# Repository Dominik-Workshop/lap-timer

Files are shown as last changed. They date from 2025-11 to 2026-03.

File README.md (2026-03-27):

# Lap Timer

 

<p align="center">
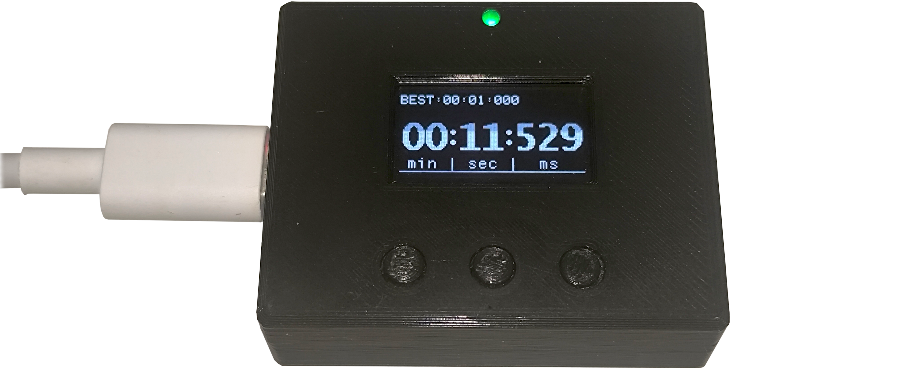
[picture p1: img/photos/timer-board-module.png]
Hero image
  
</p>

## Overview

Compact and portable **lap timer**, capable of measuring time on:

- **Closed-loop tracks** (1-gate mode)
- **Start/finish tracks** (2-gate mode)

Infrared light barriers are used as optical triggers to detect when an object crosses the start or finish line.

### Key Features

- **High accuracy** using STM32 hardware timers
- **OLED display** for showing lap times
- **Two operating modes:** 1-gate or 2-gate
- **Modulated IR system (38 kHz)** for ambient light immunity

## Project Status

**Design:** ✅ --> **Fabrication & Assembly:** ✅ --> **Bring-up:** ✅

## Electronics

Simplified arhitecture of the **Lap Timer** is shown on the block diagram bellow:
Block diagram

This project contains 3 custom PCBs:

- [**Timer board**](/pcb/timer-board/): main PCB of the system, responsible for time measurement and displaying results

<!-- <p align="center">
  <img src="images/renders/timer-board.png" width=50% alt="Timer board render"> 
</p> -->

- [**Transmitter board**](/pcb/transmitter-board/): generates the modulated IR light beam for the optical barrier

<!-- <p align="center">
  <img src="images/renders/transmitter-board.png" width=50% alt="Transmitter board render"> 
</p> -->

- [**Receiver board**](/pcb/receiver-board/): (used only in 2-gate mode) detects the IR signal and triggers the timer

<!-- <p align="center">
  <img src="images/renders/receiver-board.png" width=50% alt="Receiver board render"> 
</p> -->

## Mechanical

Each board has a custom-designed **3D printed enclosure**.

## Used Tools

- [KiCad](https://www.kicad.org/) - Schematic and PCB design
- [Autodesk Fusion 360](https://www.autodesk.com/products/fusion-360/) - 3D modeling
- [STM32CubeIDE](https://www.st.com/en/development-tools/stm32cubeide.html) - STM32 firmware development (build/flash/debug)

## Authors

- [**Dominik Pluta**](https://github.com/Dominik-Workshop):
  - **Responsibility**: [**Timer board**](/pcb/timer-board/)
- [**Mateusz Gwioździk**](https://github.com/Nojilim):
  - **Responsibility**: [**Transmitter board**](/pcb/transmitter-board/)
- [**Radek Mierzwa**](https://github.com/Radek278):
  - **Responsibility**: [**Receiver board**](/pcb/receiver-board/)

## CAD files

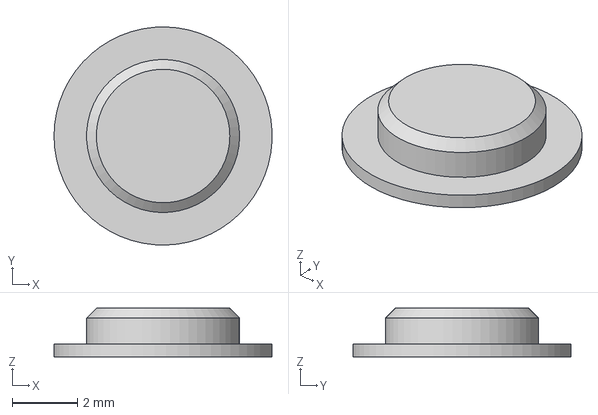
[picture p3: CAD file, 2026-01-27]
3d-models/timer-board-button.step
6.70 x 6.70 x 1.50 mm

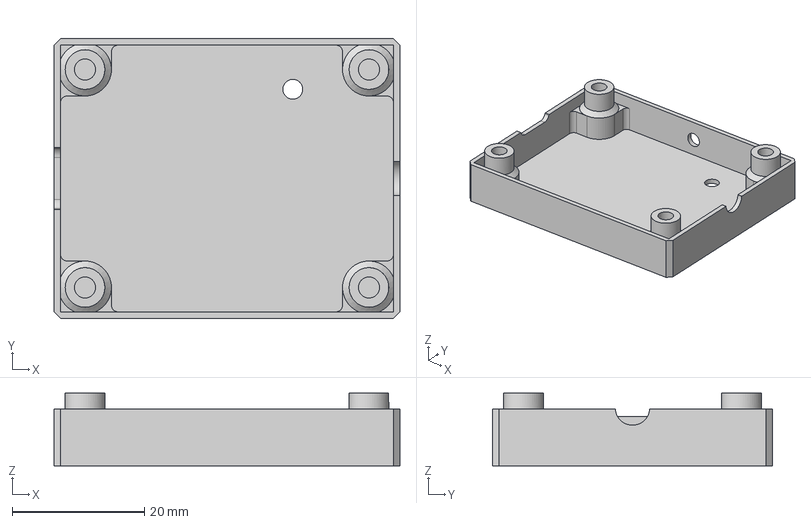
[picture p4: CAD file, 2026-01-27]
3d-models/timer-board-enclosure-bottom.step
52.4 x 42.4 x 11.0 mm

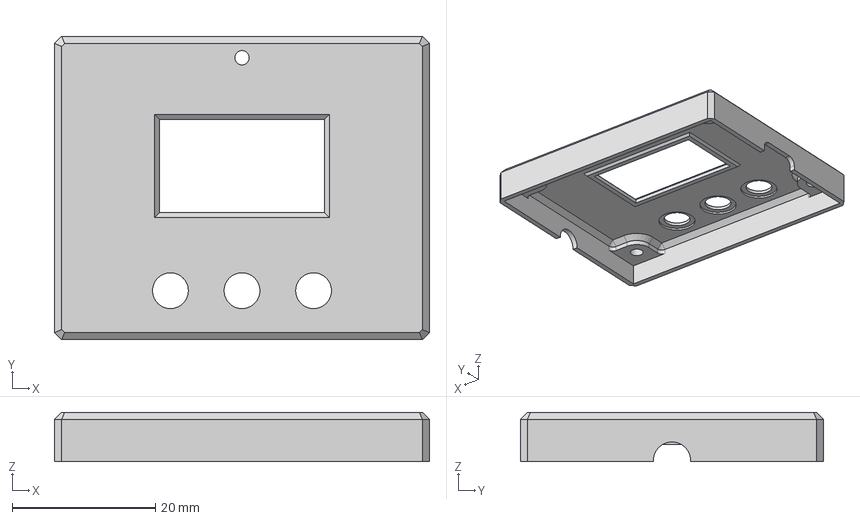
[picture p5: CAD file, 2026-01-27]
3d-models/timer-board-enclosure-top.step
52.4 x 42.4 x 6.90 mm

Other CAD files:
3d-models/timer-board-enclosure.f3z

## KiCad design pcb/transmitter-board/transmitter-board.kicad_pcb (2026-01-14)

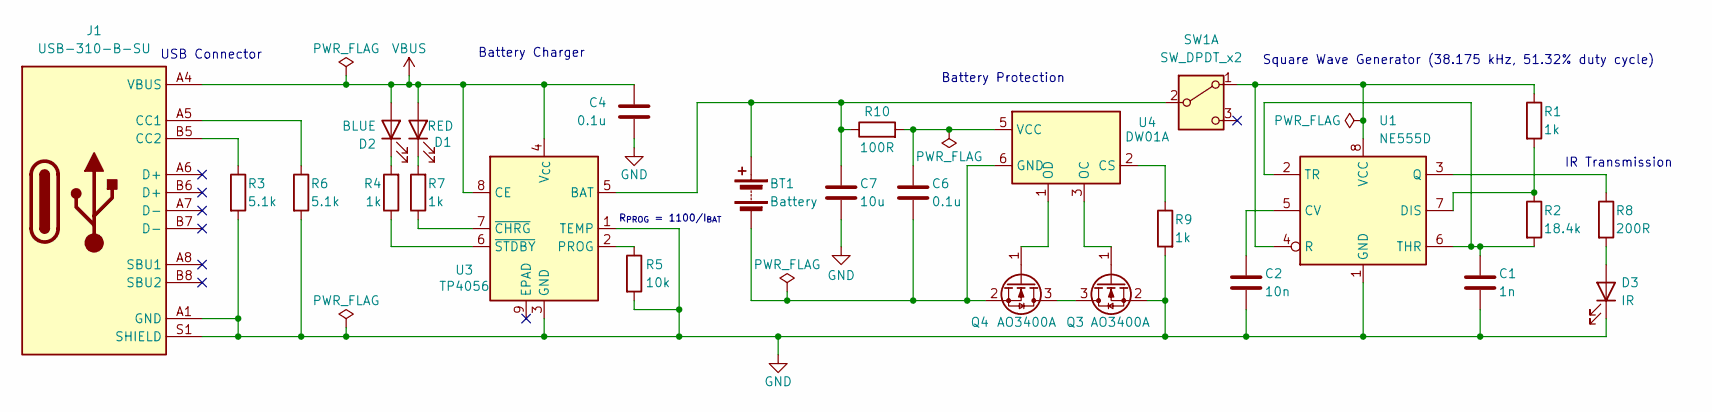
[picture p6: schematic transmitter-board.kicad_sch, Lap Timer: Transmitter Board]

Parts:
BT1: Battery; PinSocket_1x02_P2.54mm_Vertical
C1: 1n; C_0603_1608Metric_Pad1.08x0.95mm_HandSolder
C2: 10n; C_0603_1608Metric_Pad1.08x0.95mm_HandSolder
C4, C6: 0.1u; C_0603_1608Metric_Pad1.08x0.95mm_HandSolder
C7: 10u; C_0603_1608Metric_Pad1.08x0.95mm_HandSolder
D1: RED; LED_0603_1608Metric_Pad1.05x0.95mm_HandSolder
D2: BLUE; LED_0603_1608Metric_Pad1.05x0.95mm_HandSolder
D3: IR; LED_THT_Horizontal_SMD_mounted
J1: USB-C_USB-310F-B-SU; USB-C-Receptacle_USB-310-B-SU; MPN USB-310-B-SU; LCSC C309347
Q3, Q4: AO3400A; SOT-23
R1, R4, R7, R9: 1k; R_0603_1608Metric_Pad0.98x0.95mm_HandSolder
R2: 18.4k; R_0603_1608Metric_Pad0.98x0.95mm_HandSolder
R3, R6: 5.1k; R_0603_1608Metric_Pad0.98x0.95mm_HandSolder
R5: 10k; R_0603_1608Metric_Pad0.98x0.95mm_HandSolder
R8: 200R; R_0603_1608Metric_Pad0.98x0.95mm_HandSolder
R10: 100R; R_0603_1608Metric_Pad0.98x0.95mm_HandSolder
SW1: SW_DPDT_x2; SW_DPDT_CK_JS202011JCQN
U1: NE555D; SOIC-8_3.9x4.9mm_P1.27mm
U3: TP4056; SOIC-8-1EP_3.9x4.9mm_P1.27mm_EP2.41x3.3mm_ThermalVias
U4: DW01A; SOT-23-6

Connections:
GND: C1.2, C2.2, C4.2, C7.2, D3.1 (K), J1.A1 (GND), J1.A12 (GND), J1.B1 (GND), J1.B12 (GND), J1.S1 (SHIELD), Q3.2 (S), R3.2, R5.2, R6.2, R9.2, U1.1 (GND), U3.1 (TEMP), U3.3 (GND)
unnamed: BT1.1 (+), C7.1, R10.1, SW1.2 (B), U3.5 (BAT)
unnamed: BT1.2 (-), C6.2, Q4.2 (S), U4.6 (GND)
unnamed: D1.1 (K), R7.2
unnamed: D2.1 (K), R4.2
unnamed: D3.2 (A), R8.2
unnamed: J1.A5 (CC1), R6.1
unnamed: J1.B5 (CC2), R3.1
unnamed: Q3.3 (D), Q4.3 (D)
unnamed: Q3.1 (G), U4.3 (OC)
unnamed: Q4.1 (G), U4.1 (OD)
unnamed: R1.1, SW1.1 (A), U1.4 (R), U1.8 (VCC)
unnamed: C2.1, U1.5 (CV)
unnamed: R1.2, R2.1, U1.7 (DIS)
unnamed: R8.1, U1.3 (Q)
unnamed: C1.1, R2.2, U1.2 (TR), U1.6 (THR)
unnamed: R5.1, U3.2 (PROG)
unnamed: R7.1, U3.7 (~CHRG)
unnamed: R4.1, U3.6 (~STDBY)
unnamed: R9.1, U4.2 (CS)
unnamed: C6.1, R10.2, U4.5 (VCC)
VBUS: C4.1, D1.2 (A), D2.2 (A), J1.A4 (VBUS), J1.A9 (VBUS), J1.B4 (VBUS), J1.B9 (VBUS), U3.4 (V_{CC}), U3.8 (CE)

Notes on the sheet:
IR Transmission
R_{PROG} = 1100/I_{BAT}
Battery Protection
USB Connector
Battery Charger
Square Wave Generator (38.175 kHz, 51.32% duty cycle)

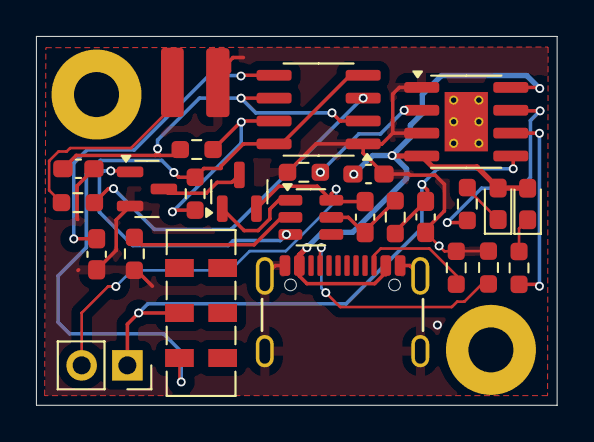
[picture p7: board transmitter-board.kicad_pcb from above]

Board: 2 copper layers, 28.9 x 20.5 mm, 26 parts (0 on the bottom side), 22 nets.

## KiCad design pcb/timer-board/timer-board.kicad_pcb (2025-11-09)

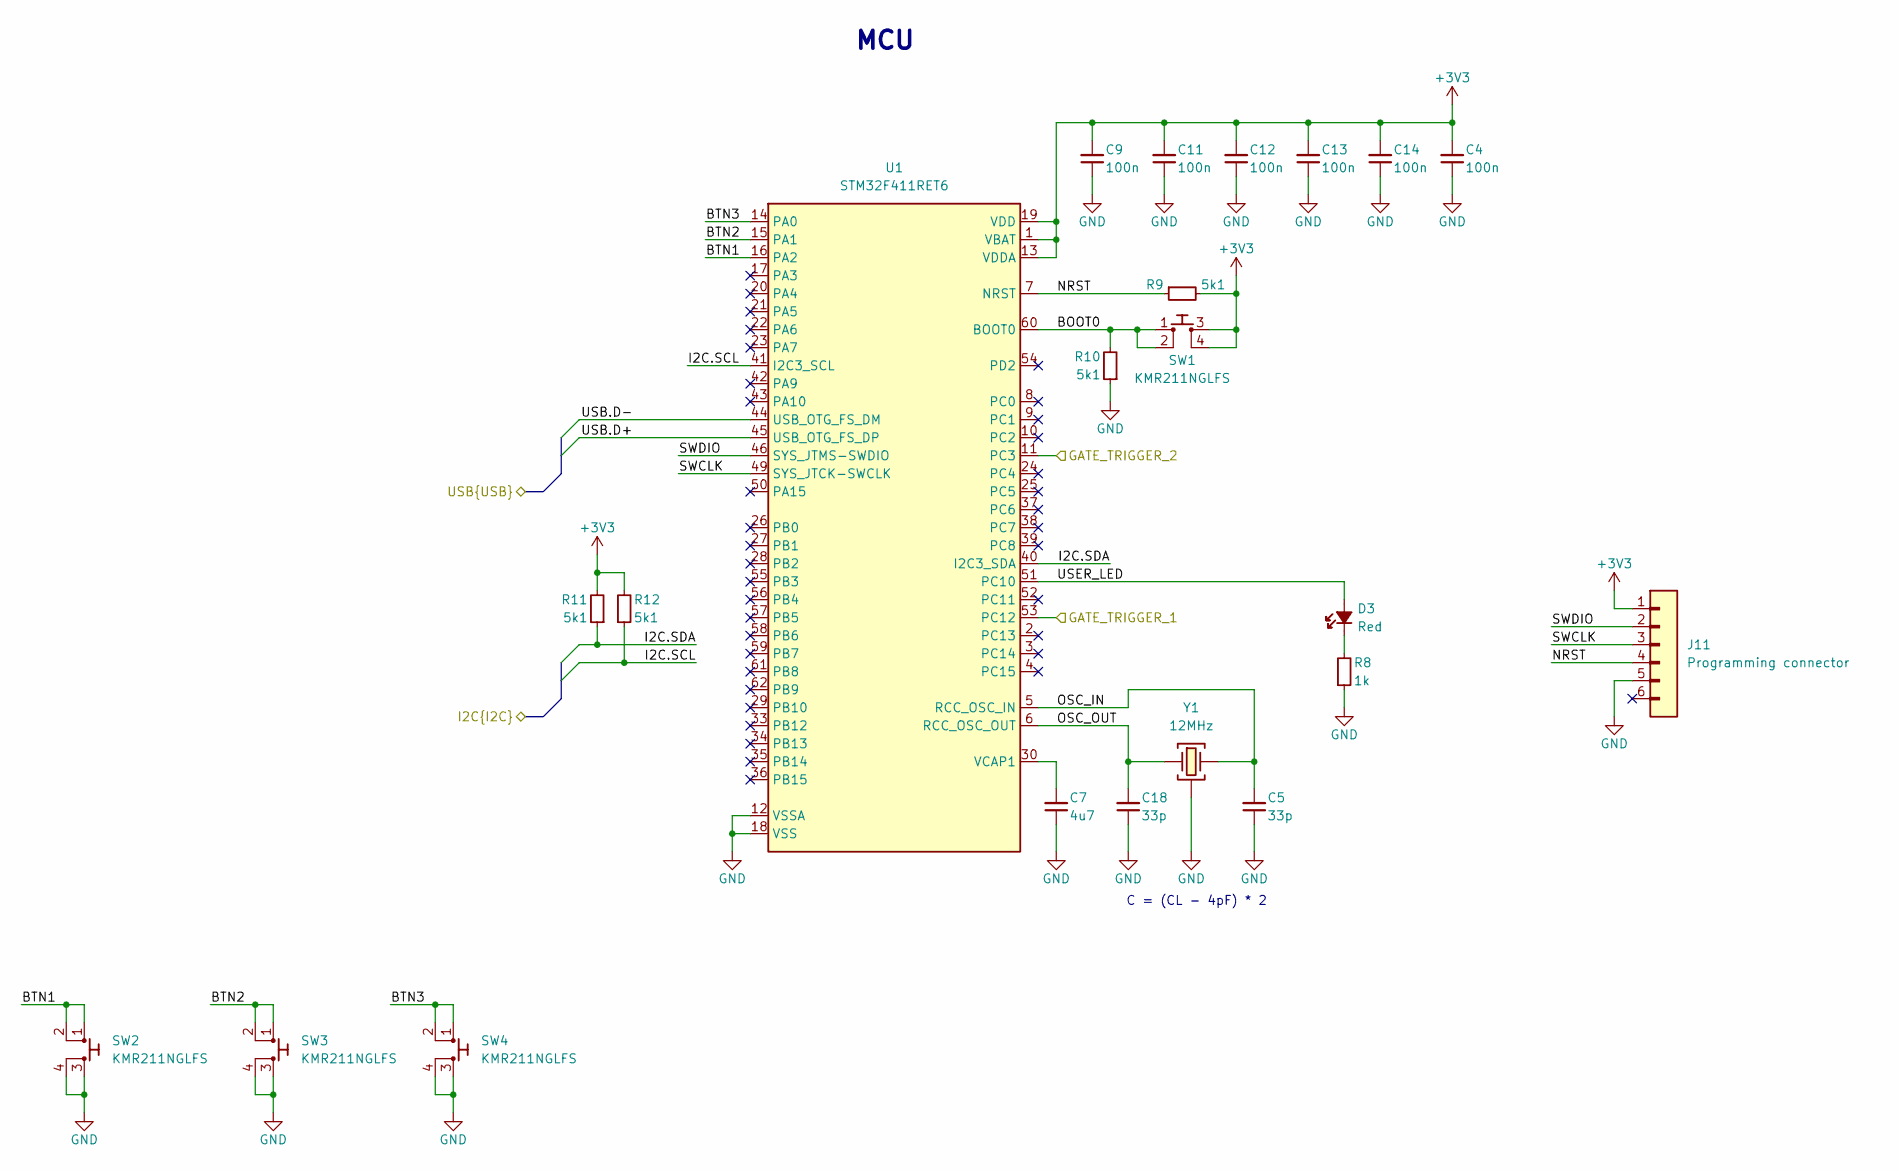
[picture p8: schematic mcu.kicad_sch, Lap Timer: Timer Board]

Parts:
C4, C9, C11, C12, C13, C14: C-100n-0402; C_0402_1005Metric; Tolerance 10%; Voltage 50V; MPN CL05B104KB54PNC; LCSC C307331
C5, C18: C-33p-0402; C_0402_1005Metric; Tolerance 5%; Voltage 50V; MPN 0402CG330J500NT; LCSC C1562
C7: C-4u7-0402; C_0402_1005Metric; Tolerance 20%; Voltage 10V; MPN CL05A475MP5NRNC; LCSC C23733
D3: LED-R-0603_KT-0603R; LED_0603_1608Metric_R; Forward voltage 1.8V-2.4V; MPN KT-0603R; LCSC C2286
J11: Programming connector; Custom-programming-connector-1x6_P1.27mm
R8: R-1k-0402; R_0402_1005Metric; Tolerance 1%; MPN 0402WGF1001TCE; LCSC C11702
R9, R10, R11, R12: R-5k1-0402; R_0402_1005Metric; Tolerance 1%; MPN 0402WGF5101TCE; LCSC C25905
SW1, SW2, SW3, SW4: SW_KMR211NGLFS; MPN KMR211NGLFS; LCSC C221676
U1: STM32F411RET6; LQFP-64_10x10mm_P0.5mm; MPN STM32F411RET6; LCSC C94355
Y1: X322512MSB4SI; Crystal_SMD_3225-4Pin_3.2x2.5mm; Frequency Tolerance ±10ppm; MPN X322512MSB4SI; LCSC C9002

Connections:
+3V3: C4.2, C9.2, C11.2, C12.2, C13.2, C14.2, J11.1, R9.2, R11.2, R12.2, SW1.3, SW1.4, U1.1 (VBAT), U1.13 (VDDA), U1.19 (VDD), U1.32 (VDD), U1.48 (VDD), U1.64 (VDD); also elsewhere on the board
/Display/I2C.SCL: R12.1, U1.41 (I2C3_SCL); also elsewhere on the board
/Display/I2C.SDA: R11.1, U1.40 (I2C3_SDA); also elsewhere on the board
/IR receiver/GATE_TRIGGER_1: U1.53 (PC12); also elsewhere on the board
/IR receiver/GATE_TRIGGER_2: U1.11 (PC3); also elsewhere on the board
/MCU/BOOT0: R10.2, SW1.1, SW1.2, U1.60 (BOOT0)
/MCU/BTN1: SW2.1, SW2.2, U1.16 (PA2)
/MCU/BTN2: SW3.1, SW3.2, U1.15 (PA1)
/MCU/BTN3: SW4.1, SW4.2, U1.14 (PA0)
/MCU/NRST: J11.4, R9.1, U1.7 (NRST)
/MCU/OSC_IN: C5.2, U1.5 (RCC_OSC_IN), Y1.3
/MCU/OSC_OUT: C18.2, U1.6 (RCC_OSC_OUT), Y1.1
/MCU/SWCLK: J11.3, U1.49 (SYS_JTCK-SWCLK)
/MCU/SWDIO: J11.2, U1.46 (SYS_JTMS-SWDIO)
/MCU/USB.D+: U1.45 (USB_OTG_FS_DP); also elsewhere on the board
/MCU/USB.D-: U1.44 (USB_OTG_FS_DM); also elsewhere on the board
/MCU/USER_LED: D3.2 (A), U1.51 (PC10)
GND: C4.1, C5.1, C7.1, C9.1, C11.1, C12.1, C13.1, C14.1, C18.1, J11.5, R8.1, R10.1, SW2.3, SW2.4, SW3.3, SW3.4, SW4.3, SW4.4, U1.12 (VSSA), U1.18 (VSS), U1.31 (VSS), U1.47 (VSS), U1.63 (VSS), Y1.2 (SH), Y1.4 (SH); also elsewhere on the board
unnamed: D3.1 (C), R8.2
unnamed: C7.2, U1.30 (VCAP1)

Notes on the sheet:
C = (CL - 4pF) * 2
MCU

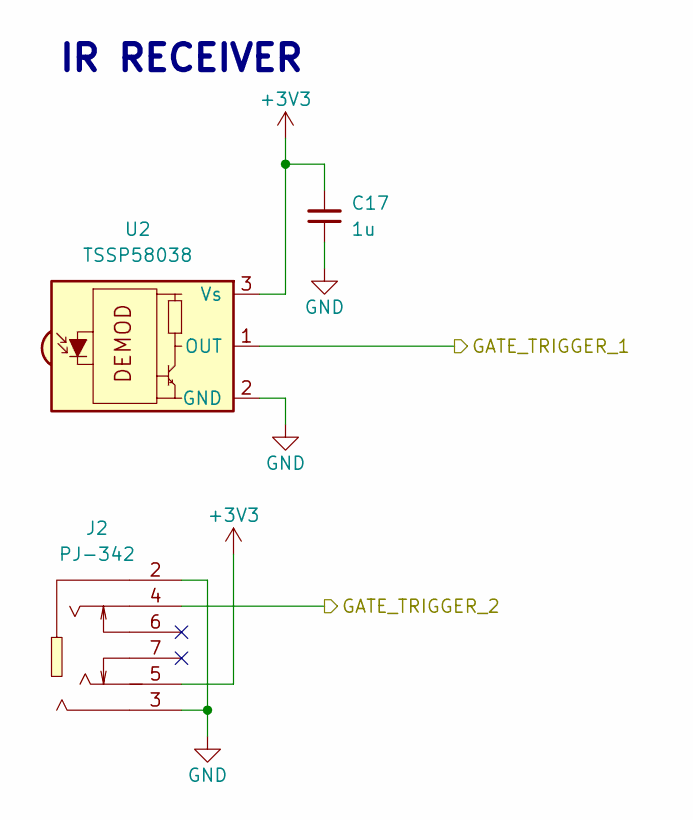
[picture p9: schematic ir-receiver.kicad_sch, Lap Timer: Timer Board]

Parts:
C17: C-1u-0402; C_0402_1005Metric; Tolerance 10%; Voltage 25V; MPN CL05A105KA5NQNC; LCSC C52923
J2: Jack_PJ-342; MPN PJ-342; LCSC C668606
U2: TSSP58038; Vishay_MINICAST-3Pin

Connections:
+3V3: C17.2, J2.5, U2.3 (Vs); also elsewhere on the board
/IR receiver/GATE_TRIGGER_1: U2.1 (OUT); also elsewhere on the board
/IR receiver/GATE_TRIGGER_2: J2.4; also elsewhere on the board
GND: C17.1, J2.2, J2.3, U2.2 (GND); also elsewhere on the board

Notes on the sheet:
IR RECEIVER

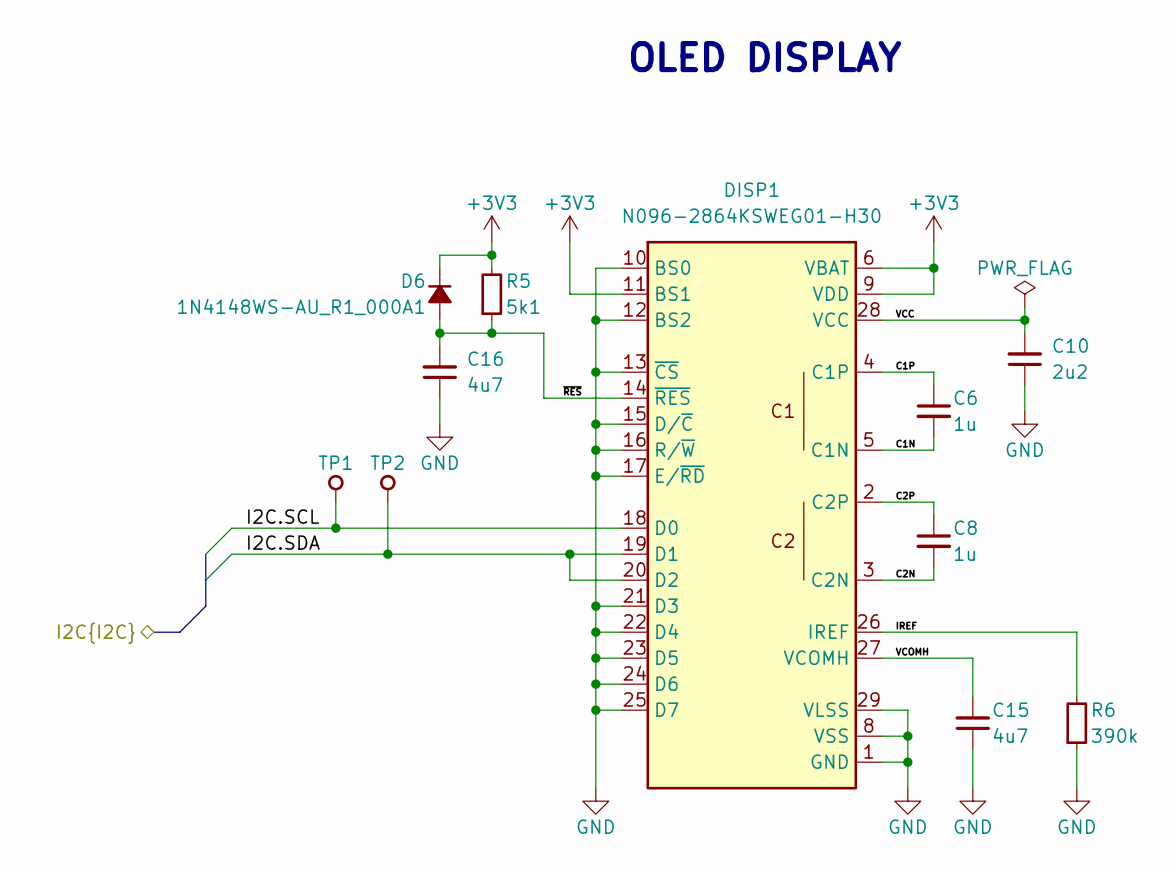
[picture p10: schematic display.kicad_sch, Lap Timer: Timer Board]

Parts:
C6, C8: C-1u-0402; C_0402_1005Metric; Tolerance 10%; Voltage 25V; MPN CL05A105KA5NQNC; LCSC C52923
C10: C-2u2-0402; C_0402_1005Metric; Tolerance 20%; Voltage 6.3V; MPN CL05A225MQ5NSNC; LCSC C12530
C15, C16: C-4u7-0402; C_0402_1005Metric; Tolerance 20%; Voltage 10V; MPN CL05A475MP5NRNC; LCSC C23733
D6: 1N4148WS-AU; D_SOD-323F; Reverse Voltage 75V; MPN 1N4148WS-AU_R1_000A1; LCSC C2999083
DISP1: N096-2864KSWEG01-H30; MPN N096-2864KSWEG01-H30
R5: R-5k1-0402; R_0402_1005Metric; Tolerance 1%; MPN 0402WGF5101TCE; LCSC C25905
R6: R-390k-0402; R_0402_1005Metric; Tolerance 1%; MPN 0402WGF3903TCE; LCSC C25782
TP1, TP2: TP_SMD_1mm

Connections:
+3V3: D6.1 (C), DISP1.6 (VBAT), DISP1.9 (VDD), DISP1.11 (BS1), R5.2; also elsewhere on the board
/Display/C1N: C6.2, DISP1.5 (C1N)
/Display/C1P: C6.1, DISP1.4 (C1P)
/Display/C2N: C8.2, DISP1.3 (C2N)
/Display/C2P: C8.1, DISP1.2 (C2P)
/Display/I2C.SCL: DISP1.18 (D0), TP1.1; also elsewhere on the board
/Display/I2C.SDA: DISP1.19 (D1), DISP1.20 (D2), TP2.1; also elsewhere on the board
/Display/IREF: DISP1.26 (IREF), R6.2
/Display/VCC: C10.2, DISP1.28 (VCC)
/Display/VCOMH: C15.2, DISP1.27 (VCOMH)
/Display/~RES: C16.2, D6.2 (A), DISP1.14 (~RES), R5.1
GND: C10.1, C15.1, C16.1, DISP1.1 (GND), DISP1.8 (VSS), DISP1.10 (BS0), DISP1.12 (BS2), DISP1.13 (~CS), DISP1.15 (D/~C), DISP1.16 (R/~W), DISP1.17 (E/~RD), DISP1.21 (D3), DISP1.22 (D4), DISP1.23 (D5), DISP1.24 (D6), DISP1.25 (D7), DISP1.29 (VLSS), DISP1.30 (GND), R6.1; also elsewhere on the board

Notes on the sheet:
OLED DISPLAY

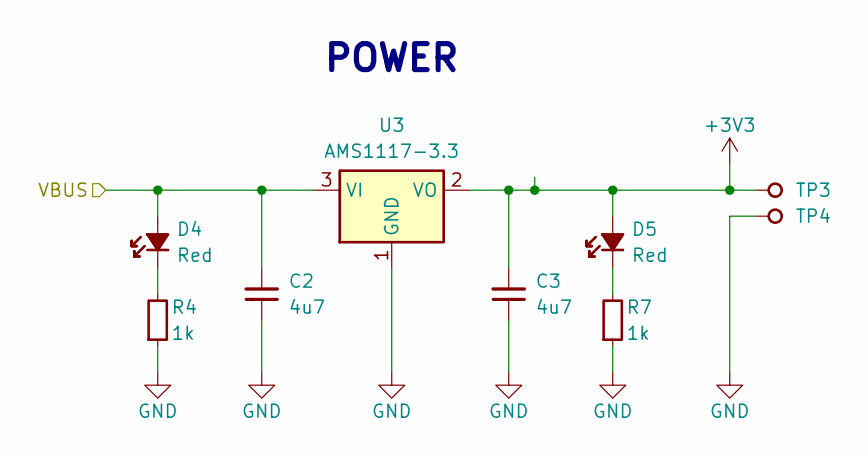
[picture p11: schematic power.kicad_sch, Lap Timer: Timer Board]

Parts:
C2, C3: C-4u7-0402; C_0402_1005Metric; Tolerance 20%; Voltage 10V; MPN CL05A475MP5NRNC; LCSC C23733
D4, D5: LED-R-0603_KT-0603R; LED_0603_1608Metric_R; Forward voltage 1.8V-2.4V; MPN KT-0603R; LCSC C2286
R4, R7: R-1k-0402; R_0402_1005Metric; Tolerance 1%; MPN 0402WGF1001TCE; LCSC C11702
TP3, TP4: TP_SMD_1mm
U3: AMS1117-3.3; SOT-223-3_TabPin2

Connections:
+3V3: C3.2, D5.2 (A), TP3.1, U3.2 (VO); also elsewhere on the board
/Power/VBUS: C2.2, D4.2 (A), U3.3 (VI); also elsewhere on the board
GND: C2.1, C3.1, R4.1, R7.1, TP4.1, U3.1 (GND); also elsewhere on the board
unnamed: D4.1 (C), R4.2
unnamed: D5.1 (C), R7.2

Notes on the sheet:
POWER

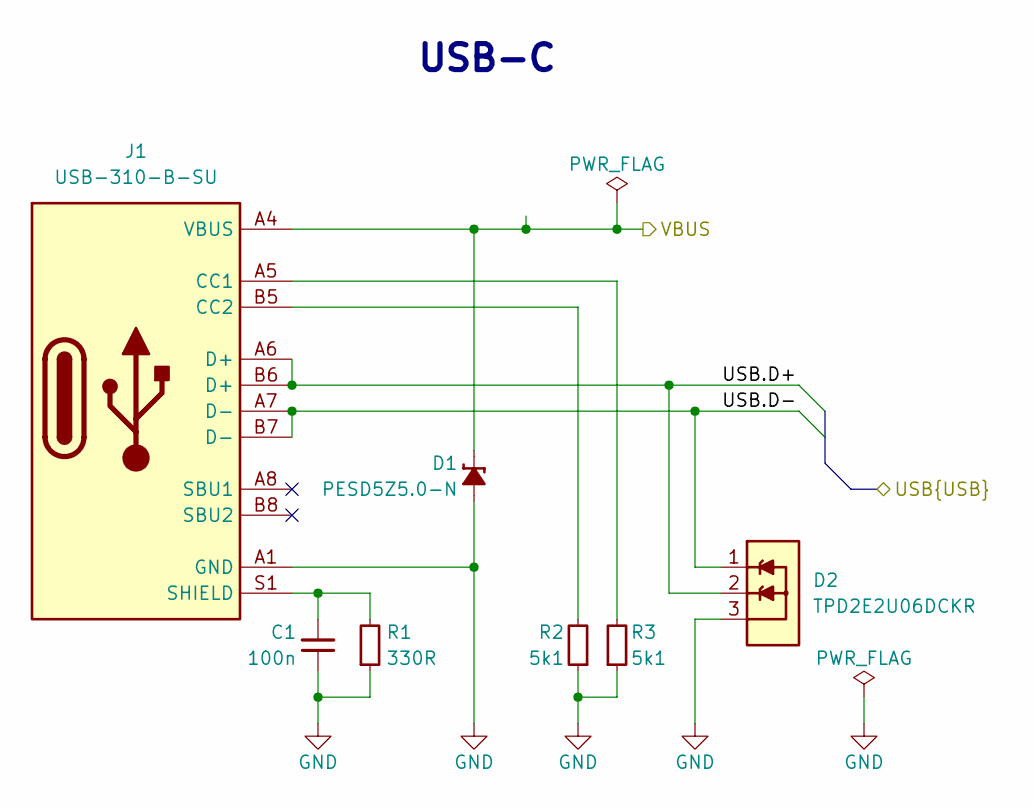
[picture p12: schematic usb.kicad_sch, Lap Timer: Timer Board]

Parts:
C1: C-100n-0402; C_0402_1005Metric; Tolerance 10%; Voltage 50V; MPN CL05B104KB54PNC; LCSC C307331
D1: PESD5Z5; D_SOD-523; MPN PESD5Z5.0-N; LCSC C920301
D2: TPD2E2U06DCKR; SOT-323; MPN TPD2E2U06DCKR; LCSC C1855726
J1: USB-C_USB-310F-B-SU; USB-C-Receptacle_USB-310-B-SU; MPN USB-310-B-SU; LCSC C309347
R1: R-330r-0402; R_0402_1005Metric; Tolerance 1%; MPN 0402WGF3300TCE; LCSC C25104
R2, R3: R-5k1-0402; R_0402_1005Metric; Tolerance 1%; MPN 0402WGF5101TCE; LCSC C25905

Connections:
/MCU/USB.D+: D2.2, J1.A6 (D+), J1.B6 (D+); also elsewhere on the board
/MCU/USB.D-: D2.1, J1.A7 (D-), J1.B7 (D-); also elsewhere on the board
/Power/VBUS: D1.1 (C), J1.A4 (VBUS), J1.A9 (VBUS), J1.B4 (VBUS), J1.B9 (VBUS); also elsewhere on the board
GND: C1.1, D1.2 (A), D2.3, J1.A1 (GND), J1.A12 (GND), J1.B1 (GND), J1.B12 (GND), R1.1, R2.1, R3.1; also elsewhere on the board
unnamed: J1.A5 (CC1), R3.2
unnamed: J1.B5 (CC2), R2.2
unnamed: C1.2, J1.S1 (SHIELD), R1.2

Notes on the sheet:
USB-C

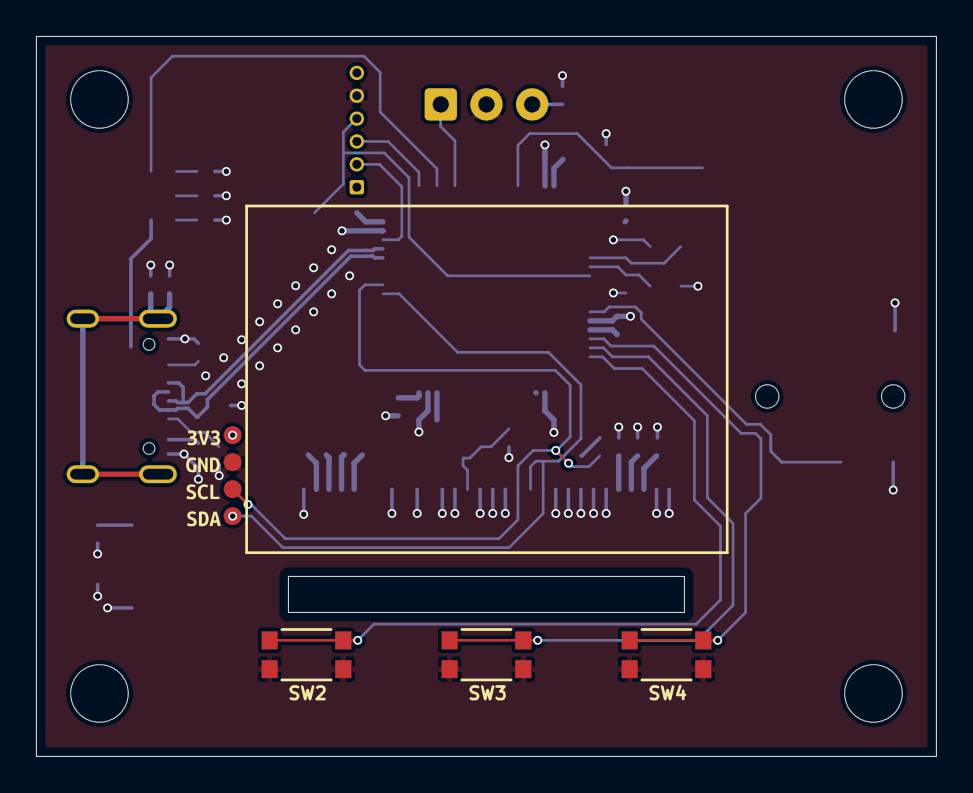
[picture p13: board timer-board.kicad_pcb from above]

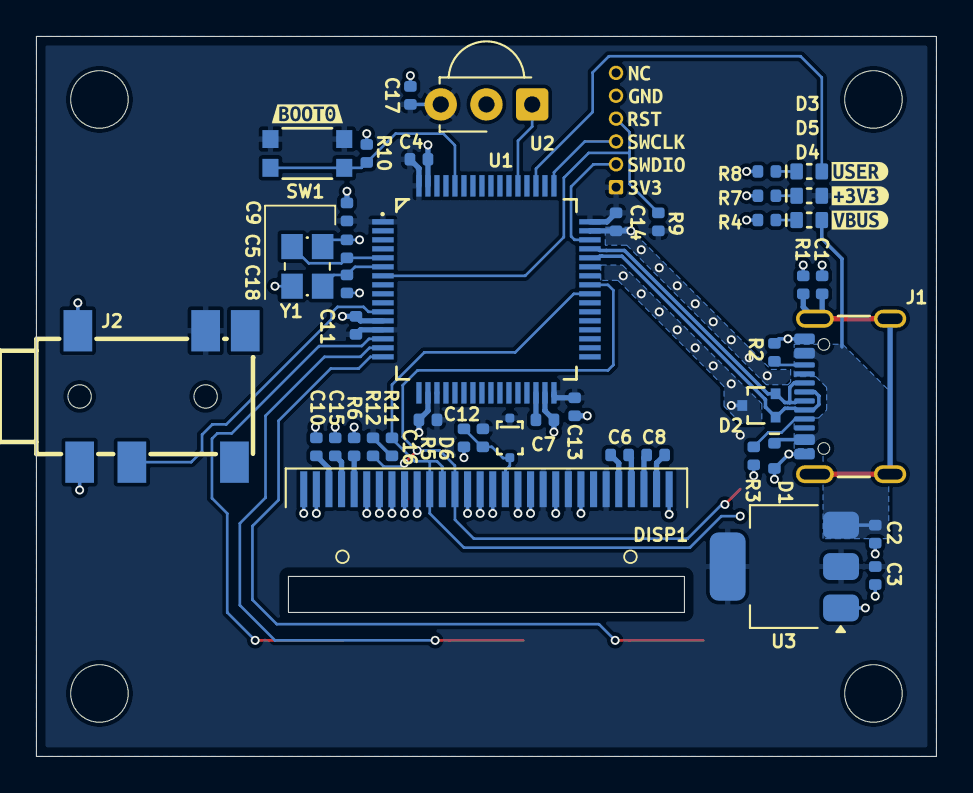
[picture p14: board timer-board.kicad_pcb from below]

Board: 2 copper layers, 50.0 x 40.0 mm, 66 parts (55 on the bottom side), 34 nets.

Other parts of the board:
kibuzzard-68E6B0E6: G***; kibuzzard-68E6B0E6
kibuzzard-68E6B17C: G***; kibuzzard-68E6B17C
kibuzzard-68E6B138: G***; kibuzzard-68E6B138
kibuzzard-68E6B152: G***; kibuzzard-68E6B152
kibuzzard-68E6B182: G***; kibuzzard-68E6B182
kibuzzard-68FD2D82: G***; kibuzzard-68FD2D82
kibuzzard-690B1D8E: G***; kibuzzard-690B1D8E
kibuzzard-690B1DCB: G***; kibuzzard-690B1DCB
kibuzzard-690B1DD3: G***; kibuzzard-690B1DD3
kibuzzard-690B1DD8: G***; kibuzzard-690B1DD8
kibuzzard-690B8D6F: G***; kibuzzard-690B8D6F
kibuzzard-691094F6: G***; kibuzzard-691094F6
kibuzzard-69109507: G***; kibuzzard-69109507
kibuzzard-69109536: G***; kibuzzard-69109536

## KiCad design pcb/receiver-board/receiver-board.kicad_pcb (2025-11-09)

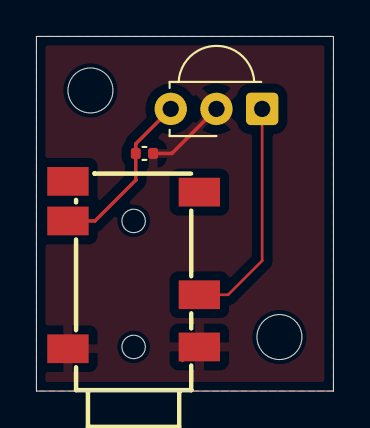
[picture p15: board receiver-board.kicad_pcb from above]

Board: 2 copper layers, 16.5 x 19.7 mm, 3 parts (0 on the bottom side), 3 nets.

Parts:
C6: C-1u-0402; C_0402_1005Metric
J2: Jack_PJ-342
U2: TSSP58038; Vishay_MINICAST-3Pin

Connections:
+3V3: C6.1, J2.5, U2.3 (Vs)
/GATE_TRIGGER2: J2.4, U2.1 (OUT)
GND: C6.2, J2.2, J2.3, U2.2 (GND)

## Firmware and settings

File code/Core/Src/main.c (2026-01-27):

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
/* Includes ------------------------------------------------------------------*/
#include "main.h"

/* USER CODE BEGIN Includes */
#include "display.h"
#include "sprites.h"
#include <stdio.h> // For sprintf
/* USER CODE END Includes */

/* USER CODE BEGIN PD */
// STM32F411RE Sector 7 address (128KB sector)
#define FLASH_STORAGE_ADDR 0x08060000
/* USER CODE END PD */

I2C_HandleTypeDef hi2c3;

TIM_HandleTypeDef htim2;

/* USER CODE BEGIN PV */
volatile uint8_t timer_state = 0; // 0: IDLE, 1: RUNNING, 2: FINISHED
volatile uint32_t captured_time_ticks = 0;
volatile uint32_t last_trigger_sys_time = 0;

uint32_t best_time_ticks = 0xFFFFFFFF; // Default to "Empty"

#define TIME_DISPLAY_X 1
#define TIME_DISPLAY_Y 22

// DISPLAY RESOLUTION MODES
typedef enum {
    RES_MODE_MS,   // Minutes : Seconds : Milliseconds  (MM:SS:MMM)
    RES_MODE_US    // Seconds : Milliseconds : Microsec (SSS:MMM:UUU) (microsec resolution down to 10us ticks)
} display_res_mode_t;

volatile display_res_mode_t display_mode = RES_MODE_MS;
/* USER CODE END PV */

void SystemClock_Config(void);
static void MX_GPIO_Init(void);
static void MX_I2C3_Init(void);
static void MX_TIM2_Init(void);
/* USER CODE BEGIN 0 */

// --- INTERRUPT CALLBACK ---
void HAL_GPIO_EXTI_Callback(uint16_t GPIO_Pin)
{
    if(GPIO_Pin == GATE_TRIGGER_1_Pin || GPIO_Pin == GATE_TRIGGER_2_Pin || GPIO_Pin == BTN1_Pin)
    {
        uint32_t now = HAL_GetTick();
        if ((now - last_trigger_sys_time) > 1000)
        {
            last_trigger_sys_time = now;

            if(timer_state == 0 || timer_state == 2) // Start
            {
                __HAL_TIM_SET_COUNTER(&htim2, 0);
                timer_state = 1;
            }
            else if(timer_state == 1) // Stop
            {
                captured_time_ticks = __HAL_TIM_GET_COUNTER(&htim2);
                timer_state = 2;
            }
        }
    }
}

// --- Helper: Erase Sector 7 and Write a single 32-bit value ---
void Save_Best_Time(uint32_t ticks)
{
    HAL_FLASH_Unlock();

    FLASH_EraseInitTypeDef EraseInitStruct;
    uint32_t SectorError;

    EraseInitStruct.TypeErase    = FLASH_TYPEERASE_SECTORS;
    EraseInitStruct.Sector       = FLASH_SECTOR_7; // Sector 7 (0x08060000)
    EraseInitStruct.NbSectors    = 1;
    EraseInitStruct.VoltageRange = FLASH_VOLTAGE_RANGE_3; // 2.7V to 3.6V

    // Note: This might freeze the CPU for 1-2 seconds!
    if (HAL_FLASHEx_Erase(&EraseInitStruct, &SectorError) == HAL_OK)
    {
        HAL_FLASH_Program(FLASH_TYPEPROGRAM_WORD, FLASH_STORAGE_ADDR, ticks);
    }

    HAL_FLASH_Lock();
}

/* Change the 4th parameter to display_font_t */
void display_formatted_time(int x, int y, uint32_t time_ms, display_font_t font) {
    char buf[20];

    uint32_t total_seconds = time_ms / 1000;
    uint32_t minutes = (total_seconds / 60) % 100;
    uint32_t seconds = total_seconds % 60;
    uint32_t milliseconds = time_ms % 1000;

    // Format string into a temporary buffer
    // MM:SS:MMM
    sprintf(buf, "%02lu:%02lu:%03lu", (unsigned long)minutes, (unsigned long)seconds, (unsigned long)milliseconds);

    // Pass the font directly to display_printf
    display_printf(x, y, DISPLAY_COLOR_WHITE, font, "%s", buf);
}

// Main Display function for the large timer (MM:SS:MMM)
void display_time_large(uint32_t time_ms){
    uint32_t ms = time_ms % 1000;
    uint32_t sec = (time_ms / 1000) % 60;
    uint32_t min = (time_ms / 60000) % 99;

    // Minutes
    display_printf(TIME_DISPLAY_X, TIME_DISPLAY_Y, DISPLAY_COLOR_WHITE, display_font_16x26, "%02lu", (unsigned long)min);
    display_bitmap(TIME_DISPLAY_X+(2*16), TIME_DISPLAY_Y+3, DISPLAY_COLOR_BLACK, bitmap_deliminator_8_16, 8, 16);

    // Seconds
    display_printf(TIME_DISPLAY_X+(2*16)+7, TIME_DISPLAY_Y, DISPLAY_COLOR_WHITE, display_font_16x26, "%02lu", (unsigned long)sec);
    display_bitmap(TIME_DISPLAY_X+(2*16)+7+(2*16), TIME_DISPLAY_Y+3, DISPLAY_COLOR_BLACK, bitmap_deliminator_8_16, 8, 16);

    // Milliseconds
    display_printf(TIME_DISPLAY_X+(2*16)+7+(2*16)+7, TIME_DISPLAY_Y, DISPLAY_COLOR_WHITE, display_font_16x26, "%03lu", (unsigned long)ms);

    display_line(0, TIME_DISPLAY_Y+37, 127, TIME_DISPLAY_Y+37, DISPLAY_COLOR_WHITE);
    display_printf(5, TIME_DISPLAY_Y+27, DISPLAY_COLOR_WHITE, display_font_7x10, "min | sec |  ms");}

// Show high-resolution time using the large font layout.
// Input: ticks = TIM2 counter (each tick = 10 us)
void display_time_highres_large_from_ticks(uint32_t ticks) {
    // Convert ticks -> total microseconds
    uint64_t total_us = (uint64_t)ticks * 10ULL;

    // Derive components
    uint32_t sec = (uint32_t)(total_us / 1000000ULL);         // seconds (may be >99)
    uint32_t ms  = (uint32_t)((total_us / 1000ULL) % 1000ULL); // milliseconds 0..999
    uint32_t micro10 = (uint32_t)((total_us % 1000ULL) / 10ULL); // 10us units 0..99

    // Cap seconds to two digits for display (if >99 you can show 99)
    if (sec > 99) sec = 99;

    // Draw using the same positions as display_time_large so it fits
    // Left: seconds (2 digits)
    display_printf(TIME_DISPLAY_X, TIME_DISPLAY_Y, DISPLAY_COLOR_WHITE, display_font_16x26, "%02lu", (unsigned long)sec);

    // colon/separator
    display_bitmap(TIME_DISPLAY_X+(2*16), TIME_DISPLAY_Y+3, DISPLAY_COLOR_BLACK, bitmap_deliminator_8_16, 8, 16);

    // Middle: milliseconds (3 digits)
    display_printf(TIME_DISPLAY_X+(2*16)+7, TIME_DISPLAY_Y, DISPLAY_COLOR_WHITE, display_font_16x26, "%03lu", (unsigned long)ms);

    // colon/separator
    display_bitmap(TIME_DISPLAY_X+(2*16)+7+(3*16), TIME_DISPLAY_Y+3, DISPLAY_COLOR_BLACK, bitmap_deliminator_8_16, 8, 16);

    // Right: microseconds in 10us units (2 digits)
    // We print %02lu so it uses two digits and fits into the rightmost digit space.
    display_printf(TIME_DISPLAY_X+(2*16)+7+(3*16)+7, TIME_DISPLAY_Y, DISPLAY_COLOR_WHITE, display_font_16x26, "%02lu", (unsigned long)micro10);

    display_line(0, TIME_DISPLAY_Y+37, 127, TIME_DISPLAY_Y+37, DISPLAY_COLOR_WHITE);
	display_printf(5, TIME_DISPLAY_Y+27, DISPLAY_COLOR_WHITE, display_font_7x10, "sec |  ms  |  us");
}

/* USER CODE END 0 */

/**
  * @brief  The application entry point.
  * @retval int
  */
int main(void)
{

  /* USER CODE BEGIN 1 */
  uint32_t btn3_press_start = 0;
  uint8_t btn3_action_done = 0;

  // BTN2 edge detection / debounce
  uint16_t prev_btn2_state = GPIO_PIN_SET; // assume not pressed (pullup)
  uint32_t btn2_press_time = 0;
  const uint32_t BTN2_DEBOUNCE_MS = 50; // debounce threshold
  /* USER CODE END 1 */

  /* MCU Configuration--------------------------------------------------------*/

  /* Reset of all peripherals, Initializes the Flash interface and the Systick. */
  HAL_Init();

  /* Configure the system clock */
  SystemClock_Config();

  /* Initialize all configured peripherals */
  MX_GPIO_Init();
  MX_I2C3_Init();
  MX_TIM2_Init();
  /* USER CODE BEGIN 2 */
  HAL_Delay(100);
  display_init();

  // --- Load Best Time from Flash ---
  best_time_ticks = *(__IO uint32_t *)FLASH_STORAGE_ADDR;

  // Sanity check: if flash was empty (0xFFFFFFFF), treat as "No Time"
  if(best_time_ticks == 0xFFFFFFFF) best_time_ticks = 0;

  display_fill(DISPLAY_COLOR_BLACK);
  display_bitmap(0, 0, DISPLAY_COLOR_BLACK, bitmap_lap_timer_logo_128_64, 128, 64);
  display_render();

  HAL_Delay(2000);
  display_fill(DISPLAY_COLOR_BLACK);
  display_render();

  HAL_TIM_Base_Start(&htim2);
  /* USER CODE END 2 */

  /* Infinite loop */
  /* USER CODE BEGIN WHILE */
  while (1)
  {
      // --- BTN3 Logic (Short Press = Reset Current, Long Press = Reset Best) ---
      if(HAL_GPIO_ReadPin(BTN3_GPIO_Port, BTN3_Pin) == GPIO_PIN_RESET) // Button is Pressed (active low)
      {
          if(btn3_press_start == 0) {
              btn3_press_start = HAL_GetTick(); // Start timer
          }

          // Check for Long Press while holding
          if((HAL_GetTick() - btn3_press_start > 2000) && !btn3_action_done)
          {
              best_time_ticks = 0; // Reset variable
              Save_Best_Time(0);   // Erase Flash

              // Visual Feedback
              display_fill(DISPLAY_COLOR_BLACK);
              display_printf(10, 30, DISPLAY_COLOR_WHITE, display_font_7x10, "RESET BEST!");
              display_render();
              HAL_Delay(1000);

              btn3_action_done = 1; // Prevent repeated triggers
          }
      }
      else // Button is Released
      {
          // If we were pressing the button...
          if(btn3_press_start != 0)
          {
              // Check if it was a Short Press (and not already handled as a long press)
              if(!btn3_action_done && (HAL_GetTick() - btn3_press_start < 2000))
              {
                  // --- SHORT PRESS ACTION: Reset Current Timer ---
                  timer_state = 0;        // Go back to IDLE
                  captured_time_ticks = 0; // Clear captured result
                  __HAL_TIM_SET_COUNTER(&htim2, 0); // Reset hardware timer
              }

              // Reset flags
              btn3_press_start = 0;
              btn3_action_done = 0;
          }
      }
      // ---------------------------------------

      // --- BTN2: toggle resolution on a short press (debounced) ---
      uint16_t curr_btn2 = HAL_GPIO_ReadPin(BTN2_GPIO_Port, BTN2_Pin);
      if(curr_btn2 == GPIO_PIN_RESET && prev_btn2_state == GPIO_PIN_SET) {
          // button pressed down
          btn2_press_time = HAL_GetTick();
      }
      else if(curr_btn2 == GPIO_PIN_SET && prev_btn2_state == GPIO_PIN_RESET) {
          // button released -> consider it a valid press if held > debounce
          if(btn2_press_time != 0 && (HAL_GetTick() - btn2_press_time) > BTN2_DEBOUNCE_MS) {
              // toggle display mode
              if(display_mode == RES_MODE_MS) display_mode = RES_MODE_US;
              else display_mode = RES_MODE_MS;

              display_fill(DISPLAY_COLOR_BLACK);
              // provide small feedback
//              if(display_mode == RES_MODE_MS) {
//                  display_printf(10, 30, DISPLAY_COLOR_WHITE, display_font_7x10, "MODE: MM:SS:MS");
//              } else {
//                  display_printf(10, 30, DISPLAY_COLOR_WHITE, display_font_7x10, "MODE: SS:MS:US");
//              }
//              display_render();
//              HAL_Delay(600);
          }
          btn2_press_time = 0;
      }
      prev_btn2_state = curr_btn2;
      // ---------------------------------------

      // --- Timer Display Logic ---
      uint32_t current_ticks = 0;

      if(timer_state == 1)
      {
          // Running
          current_ticks = __HAL_TIM_GET_COUNTER(&htim2);

          if(display_mode == RES_MODE_MS) {
              // convert ticks (10us) -> ms
              display_time_large(current_ticks / 100);
          } else {
              // show high-res mode directly from ticks
        	  display_time_highres_large_from_ticks(current_ticks);
          }
      }
      else if(timer_state == 2)
      {
          // Finished
          if(display_mode == RES_MODE_MS) {
              display_time_large(captured_time_ticks / 100);
          } else {
        	  display_time_highres_large_from_ticks(captured_time_ticks);
          }

          // Check for New Record (Logic runs once when state hits 2)
          static uint8_t saved_flag = 0;
          static uint32_t last_captured = 0;

          if(captured_time_ticks != last_captured) {
              saved_flag = 0; // New lap detected
              last_captured = captured_time_ticks;
          }

          if(saved_flag == 0)
          {
              // If valid time (>1 sec) AND (First run OR Better time)
              if(captured_time_ticks > 100000 && (best_time_ticks == 0 || captured_time_ticks < best_time_ticks))
              {
                  best_time_ticks = captured_time_ticks;

                  display_printf(0, 0, DISPLAY_COLOR_WHITE, display_font_6x8, "SAVING...     ");
                  display_render();

                  Save_Best_Time(best_time_ticks);
              }
              saved_flag = 1; // Mark as processed
          }
      }
      else
      {
          // Idle
          if(display_mode == RES_MODE_MS) {
              display_time_large(0);
          } else {
        	  display_time_highres_large_from_ticks(0);
          }
      }

      // --- Render Best Time (top-left) ---
      display_printf(0, 0, DISPLAY_COLOR_WHITE, display_font_6x8, "BEST:");
      if(best_time_ticks > 0 && best_time_ticks != 0xFFFFFFFF) {
          if(display_mode == RES_MODE_MS) {
              // best_time_ticks -> ms
              display_formatted_time(30, 0, best_time_ticks/100, display_font_6x8);
          } else {
              // show best time in highres: compute total_us and print SS:MMM:UUU with small font
              uint64_t total_us = (uint64_t)best_time_ticks * 10ULL;
              uint32_t us = total_us % 1000;
              uint32_t ms = (total_us / 1000) % 1000;
              uint32_t sec = (uint32_t)(total_us / 1000000ULL);
              display_printf(30, 0, DISPLAY_COLOR_WHITE, display_font_6x8, "%03lu:%03lu:%03lu",
                             (unsigned long)sec, (unsigned long)ms, (unsigned long)us);
          }
      } else {
          display_printf(30, 0, DISPLAY_COLOR_WHITE, display_font_6x8, "--:--:---");
      }

      display_render();

    /* USER CODE END WHILE */

    /* USER CODE BEGIN 3 */
  }
  /* USER CODE END 3 */
}

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


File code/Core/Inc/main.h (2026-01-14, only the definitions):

#define GATE_TRIGGER_2_Pin GPIO_PIN_3
#define GATE_TRIGGER_2_GPIO_Port GPIOC
#define GATE_TRIGGER_2_EXTI_IRQn EXTI3_IRQn
#define BTN3_Pin GPIO_PIN_0
#define BTN3_GPIO_Port GPIOA
#define BTN2_Pin GPIO_PIN_1
#define BTN2_GPIO_Port GPIOA
#define BTN1_Pin GPIO_PIN_2
#define BTN1_GPIO_Port GPIOA
#define BTN1_EXTI_IRQn EXTI2_IRQn
#define USER_LED_Pin GPIO_PIN_10
#define USER_LED_GPIO_Port GPIOC
#define GATE_TRIGGER_1_Pin GPIO_PIN_12
#define GATE_TRIGGER_1_GPIO_Port GPIOC
#define GATE_TRIGGER_1_EXTI_IRQn EXTI15_10_IRQn

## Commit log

2025-10-19 Initialize KiCad projects, setup design rules, pre-defined sizes and net classes
    [receiver-board.kicad_pcb, receiver-board.kicad_sch, timer-board.kicad_pcb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]
2025-11-02 Add transmitter-board schematics
    [transmitter-board.kicad_pcb, transmitter-board.kicad_sch]
2025-11-02 Change package to 0603
    [transmitter-board.kicad_sch]
2025-11-02 Add receiver-board schematic and pcb
    [receiver-board.kicad_pcb, receiver-board.kicad_sch]
2025-11-03 Add transmitter-board pcb
    [transmitter-board.kicad_pcb, transmitter-board.kicad_sch]
2025-11-04 Change hole size under TP4056 and change battery connector to THT.
    [transmitter-board.kicad_pcb, transmitter-board.kicad_sch]
2025-11-08 Added capacitor and changed jack on receiver board
    [receiver-board.kicad_pcb, receiver-board.kicad_sch]
2025-11-08 replace whole on receiver board
    [receiver-board.kicad_pcb]
2025-11-09 Clear DRC, move audio jack and resize the board, update title block author and date
    [receiver-board.kicad_pcb, receiver-board.kicad_sch]
2025-11-09 Change USB and battery connector
    [transmitter-board.kicad_pcb, transmitter-board.kicad_sch]
2025-11-09 Move USB
    [transmitter-board.kicad_pcb]
2025-11-09 Change R5 value
    [transmitter-board.kicad_sch]
2025-11-09 Start schematic design of the timer board, add MCU, USB, IR receiver and OLED
    [display.kicad_sch, ir-receiver.kicad_sch, mcu.kicad_sch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]
2025-11-09 Connect OLED display, position main components
    [display.kicad_sch, mcu.kicad_sch, power.kicad_sch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]
2025-11-09 Layout power planes and different signals
    [display.kicad_sch, ir-receiver.kicad_sch, mcu.kicad_sch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]
2025-11-09 Finish uncompleted schematic sections, layout most of the PCB
    [display.kicad_sch, ir-receiver.kicad_sch, mcu.kicad_sch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]
2025-11-09 Add 3.5mm jack, fix BOOT0 connection
    [ir-receiver.kicad_sch, mcu.kicad_sch, timer-board.kicad_pcb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]
2025-11-09 Add I2C pull-up, IR receiver decoupling, LED labels, clear ERC and DRC
    [display.kicad_sch, ir-receiver.kicad_sch, mcu.kicad_sch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]
2025-12-21 Edited transmitter-board schematic
    [transmitter-board.kicad_pcb, transmitter-board.kicad_sch]
2025-12-21 Change schematic look
    [transmitter-board.kicad_sch]
2025-12-21 Refactor transmitter-board schematic
    [transmitter-board.kicad_sch]
2025-12-21 Final refactor transmitter-board schematic
    [transmitter-board.kicad_sch]
2025-12-21 Clear ERC and DRC
    [transmitter-board.kicad_pcb, transmitter-board.kicad_sch]
2026-01-14 Setup pin configuration with appropriate names
2026-01-14 WIP: Use pin interrupt
2026-01-14 Test interrupt triggering with BTN1
2026-01-14 Test main sensor triggering
2026-01-14 Display dummy time, increase I2C speed
2026-01-14 First working timer
2026-01-14 Add debouncing at stop, add reset button
2026-01-14 Add short/long reset button press functions, add additional timer trigger pins - BTN1 and GATE_TRIG_2
    [main.c]
2026-01-14 Fix floating GATE_TRIGER_2 pin
    [lap-timer.ioc, main.c]
2026-01-27 Add Timer Board enclosure 3D model
    [timer-board-button.step, timer-board-enclosure-bottom.step, timer-board-enclosure-top.step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]
2026-03-27 Add timer module photo to README

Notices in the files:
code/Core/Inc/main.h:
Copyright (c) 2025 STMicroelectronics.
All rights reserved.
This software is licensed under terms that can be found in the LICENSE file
